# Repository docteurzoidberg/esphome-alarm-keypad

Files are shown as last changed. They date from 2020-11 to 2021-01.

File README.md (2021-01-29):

# Esphome Alarm Keypad

! README IN PROGRESS !

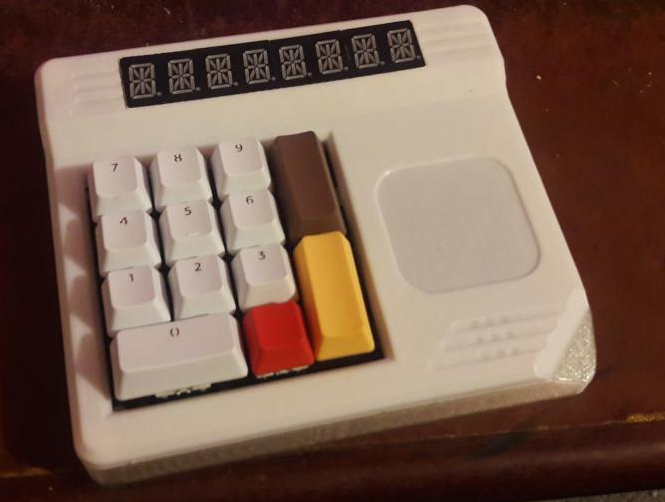
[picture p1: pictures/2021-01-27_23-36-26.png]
Alarm Keypad Picture


The Alarm Keypad is an interface to the Home Assistant Alarm Control Panel

//TODO: insert link here of ha alarm integration

Goal is to have a nice alarm control panel with lights, displays, rfid tag reader and a backup keypad to arm/disarm the Home Assistant alarm.

## Prototype video

protovideodemo (http://www.youtube.com/watch?v=kQHlJRchfG0 "prototype working with all features !")

## Features

- 13 key keyboard with mechanical switches . behind a pcf8574 i2c i/o expander
- per key adressable rgb backlight (13)
- pn532 rfid reader
- adressable led strip for case backlight
- adressable led ring for rfid feedback
- two 4 character alphanum displays with ht16k33 backpacks
- RTTTL sound output

## Hardware:

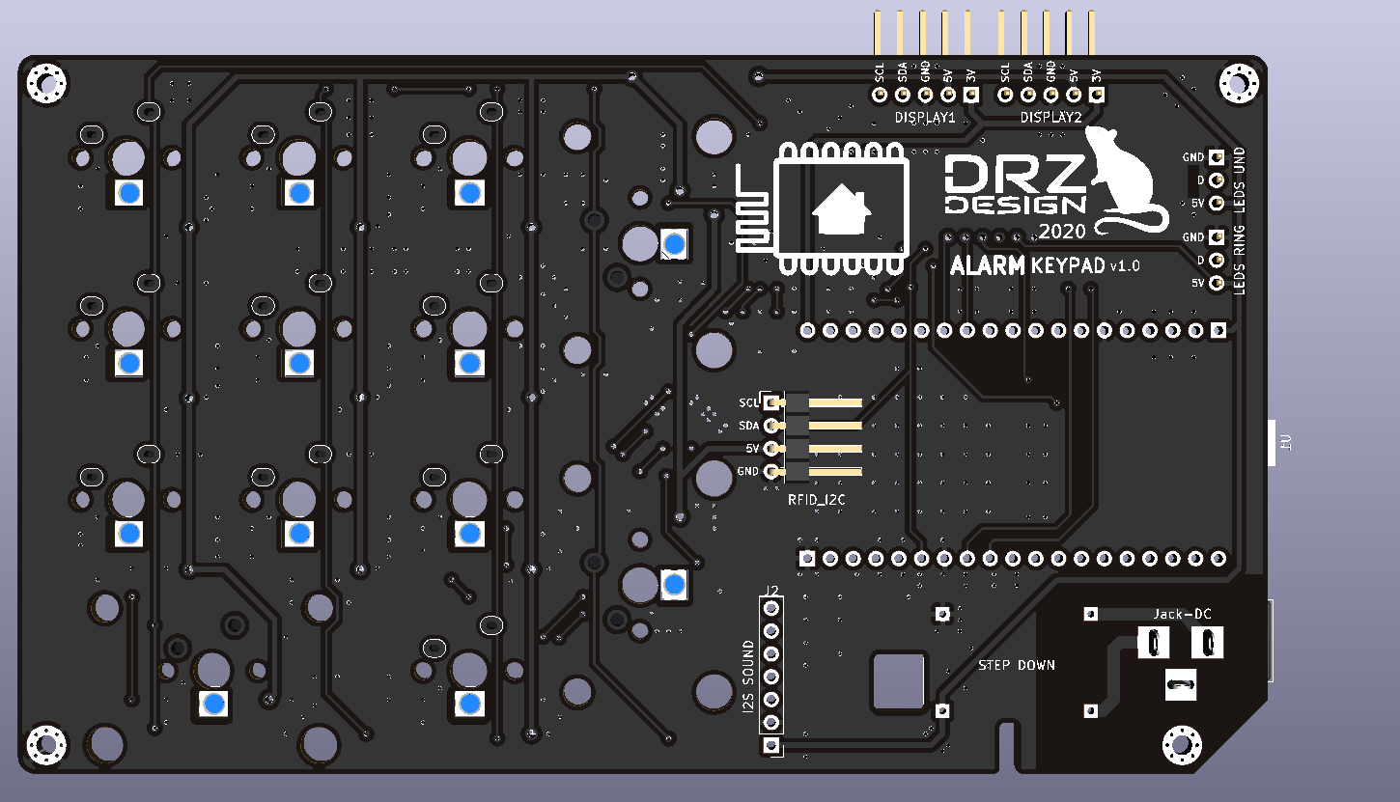
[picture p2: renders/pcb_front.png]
pcb front

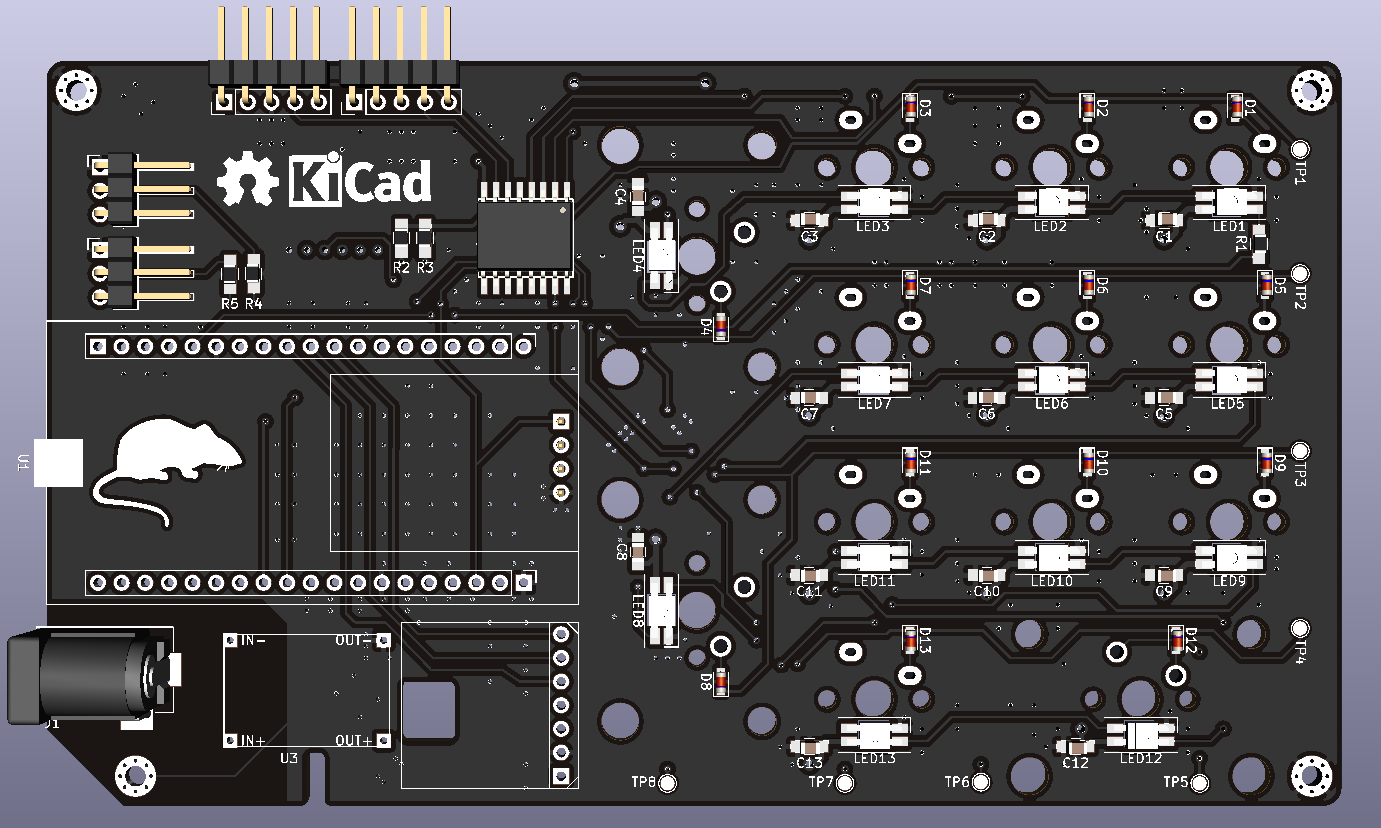
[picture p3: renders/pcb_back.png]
pcb_back


kicad/ contain the custom made pcb with all i/o from and to the esp, integrating the keypad with per key smd rgb backlight.

## Software:

//TODO: link to my-esphome github repo

### boot

    loading sequence on leds and screen

### connected

    show alarm state (armed/disarmed and so on)

### disconnected

    show "ERROR"

### rfid scan

    animate rfid led ring
    HA tag scanned service, changing alarm state if correct tag?

### key press

    flash key backlight in one color
    enter typing state

### typing

    show "code ?" + asterisk each pressed key until 4
    when 4 (allowed) keys pressed enter code check state
    start timer to enter typing timeout if no key pressed in X seconds

### typing timeout

    do something animated with case and keypad leds
    return back to alarm state mode

### code check

    display "check..." until we got a state change in HA alarm, or entering a 5sec timeout
    do something animated with case and keypad leds
### code check timeout

    HA alarm state didn't changed so the code is wrong or there is a problem
    display "FAIL" for 3 sec and go back to alarm state mode
    do something animated with case and keypad leds

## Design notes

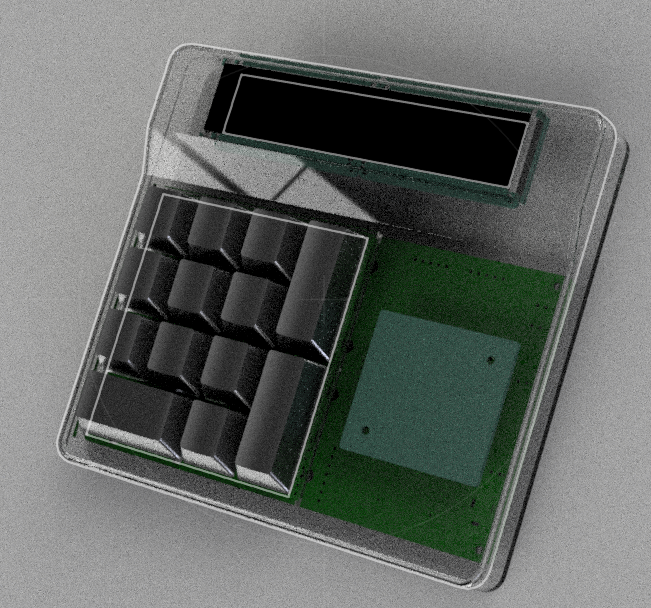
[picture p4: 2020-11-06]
renders/case3.png

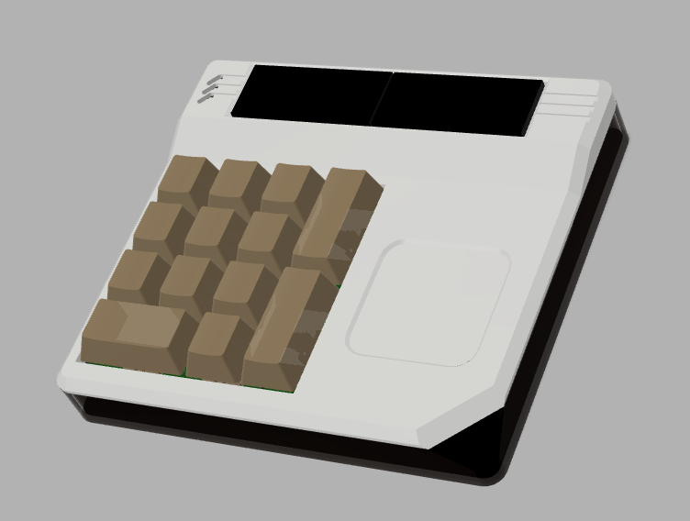
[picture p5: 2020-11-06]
renders/case2.png

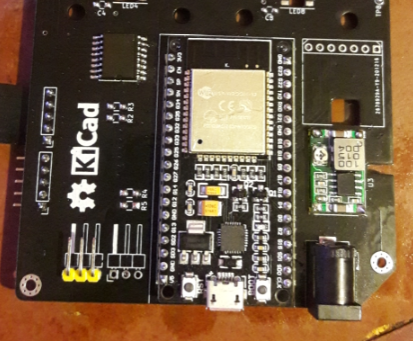
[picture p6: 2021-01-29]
pictures/2021-01-09_18.17.33.png

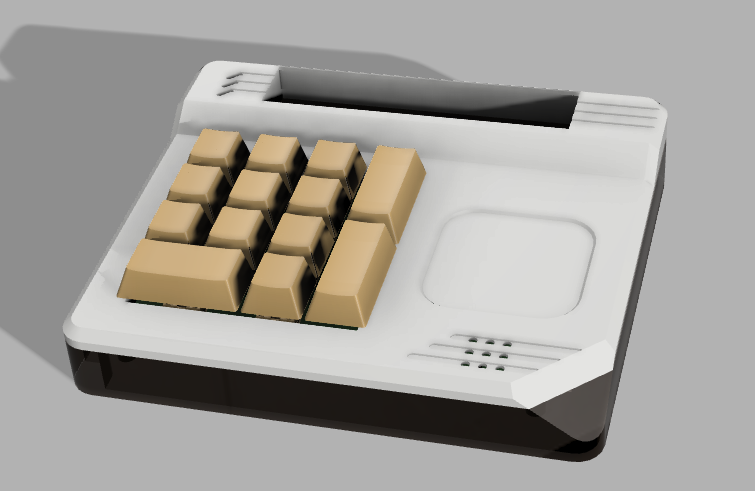
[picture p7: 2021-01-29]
renders/case.png

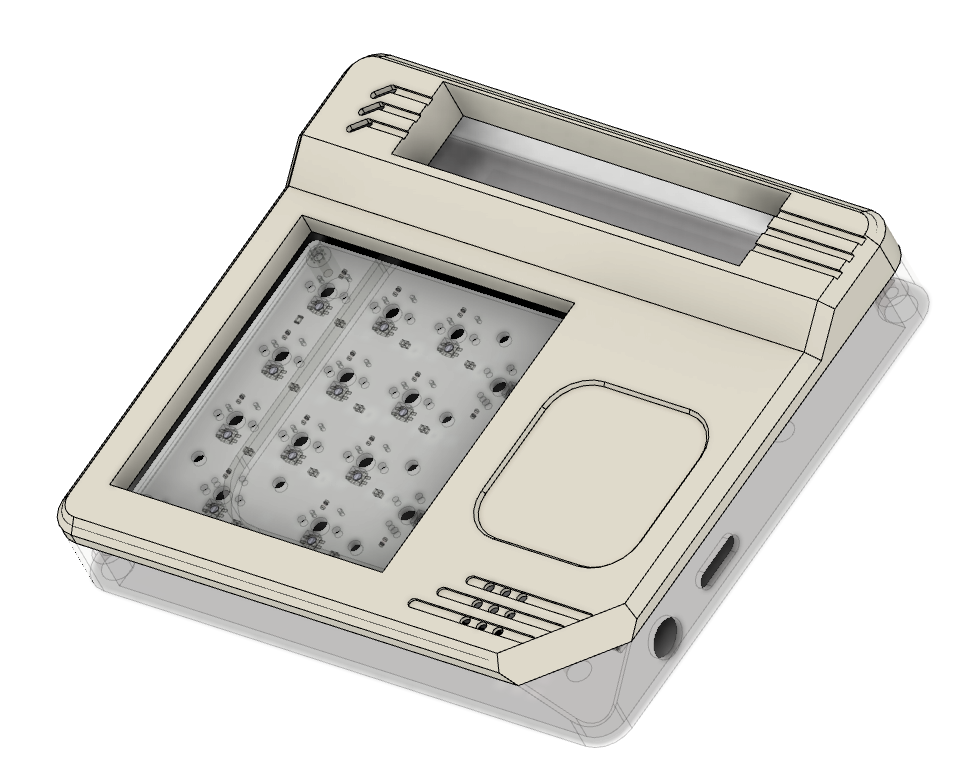
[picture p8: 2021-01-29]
renders/case_front.png

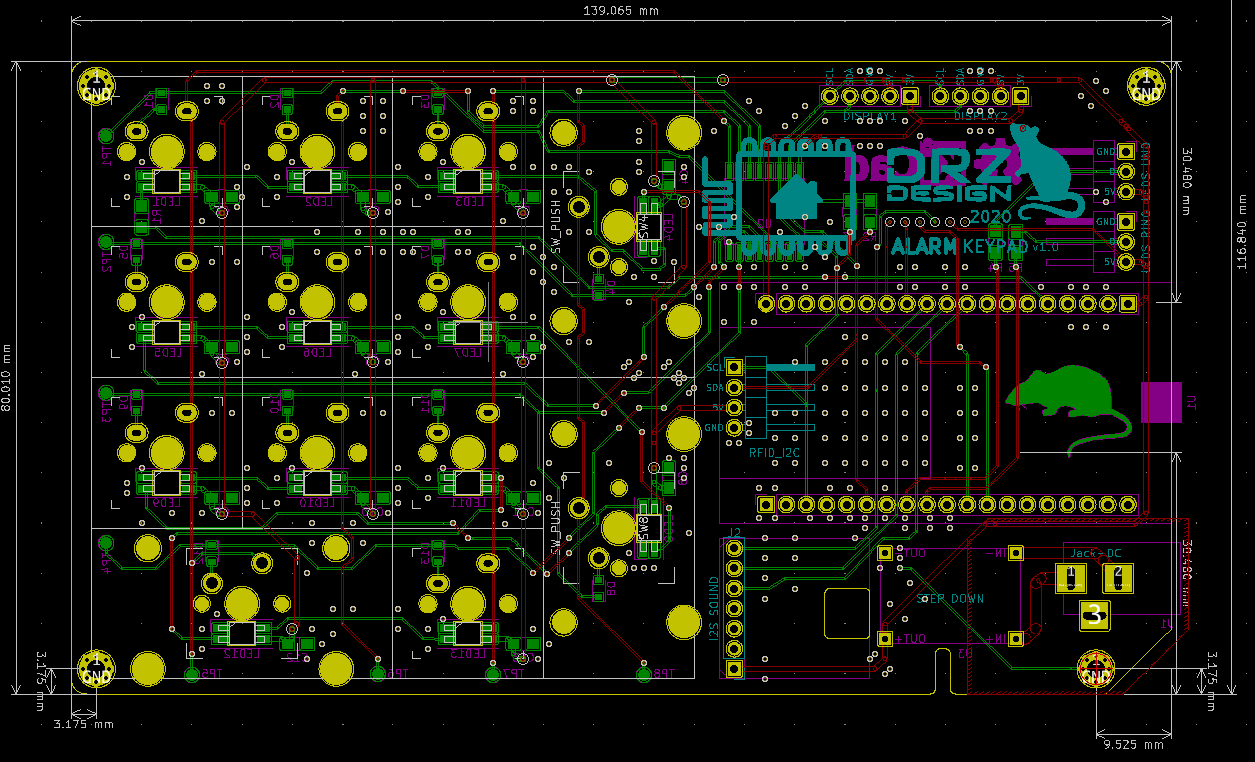
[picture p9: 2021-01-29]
renders/pcb.png

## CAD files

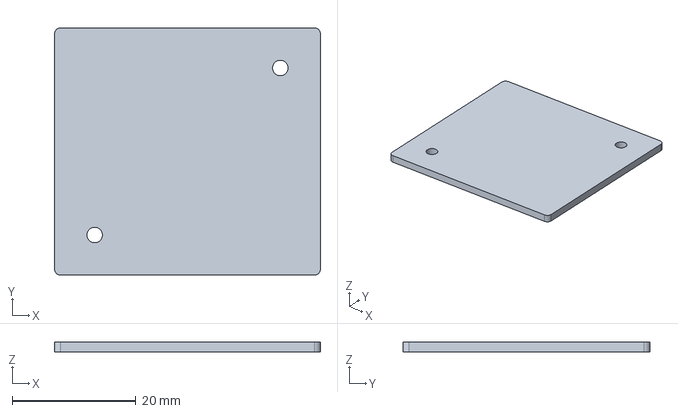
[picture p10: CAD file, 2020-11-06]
3d models/rfid module v2.step
43.0 x 40.0 x 1.60 mm

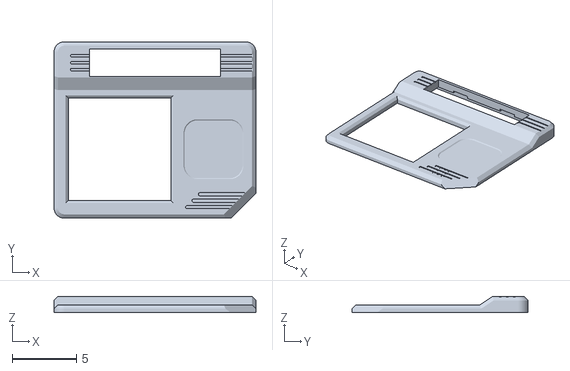
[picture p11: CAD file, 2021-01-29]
case/stl/case_haut.stl
15.7 x 13.7 x 1.26

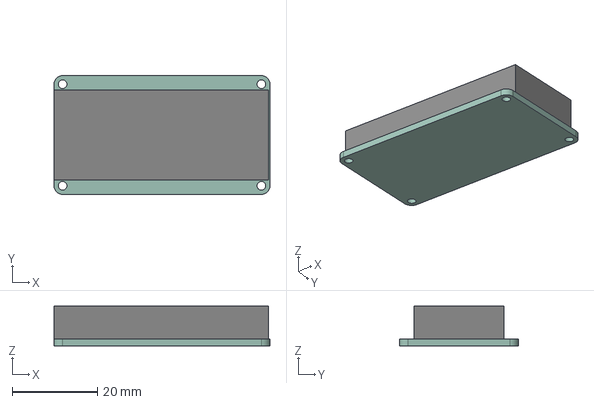
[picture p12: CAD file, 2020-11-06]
3d models/ht16k33 quad alpha backback v5.step
50.8 x 27.9 x 9.40 mm

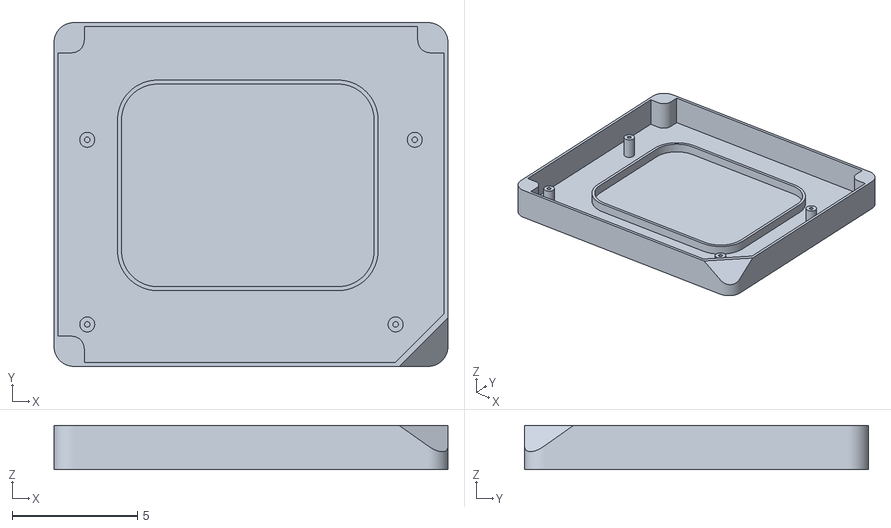
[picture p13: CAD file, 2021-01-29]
case/stl/case_bas.stl
15.7 x 13.7 x 1.76

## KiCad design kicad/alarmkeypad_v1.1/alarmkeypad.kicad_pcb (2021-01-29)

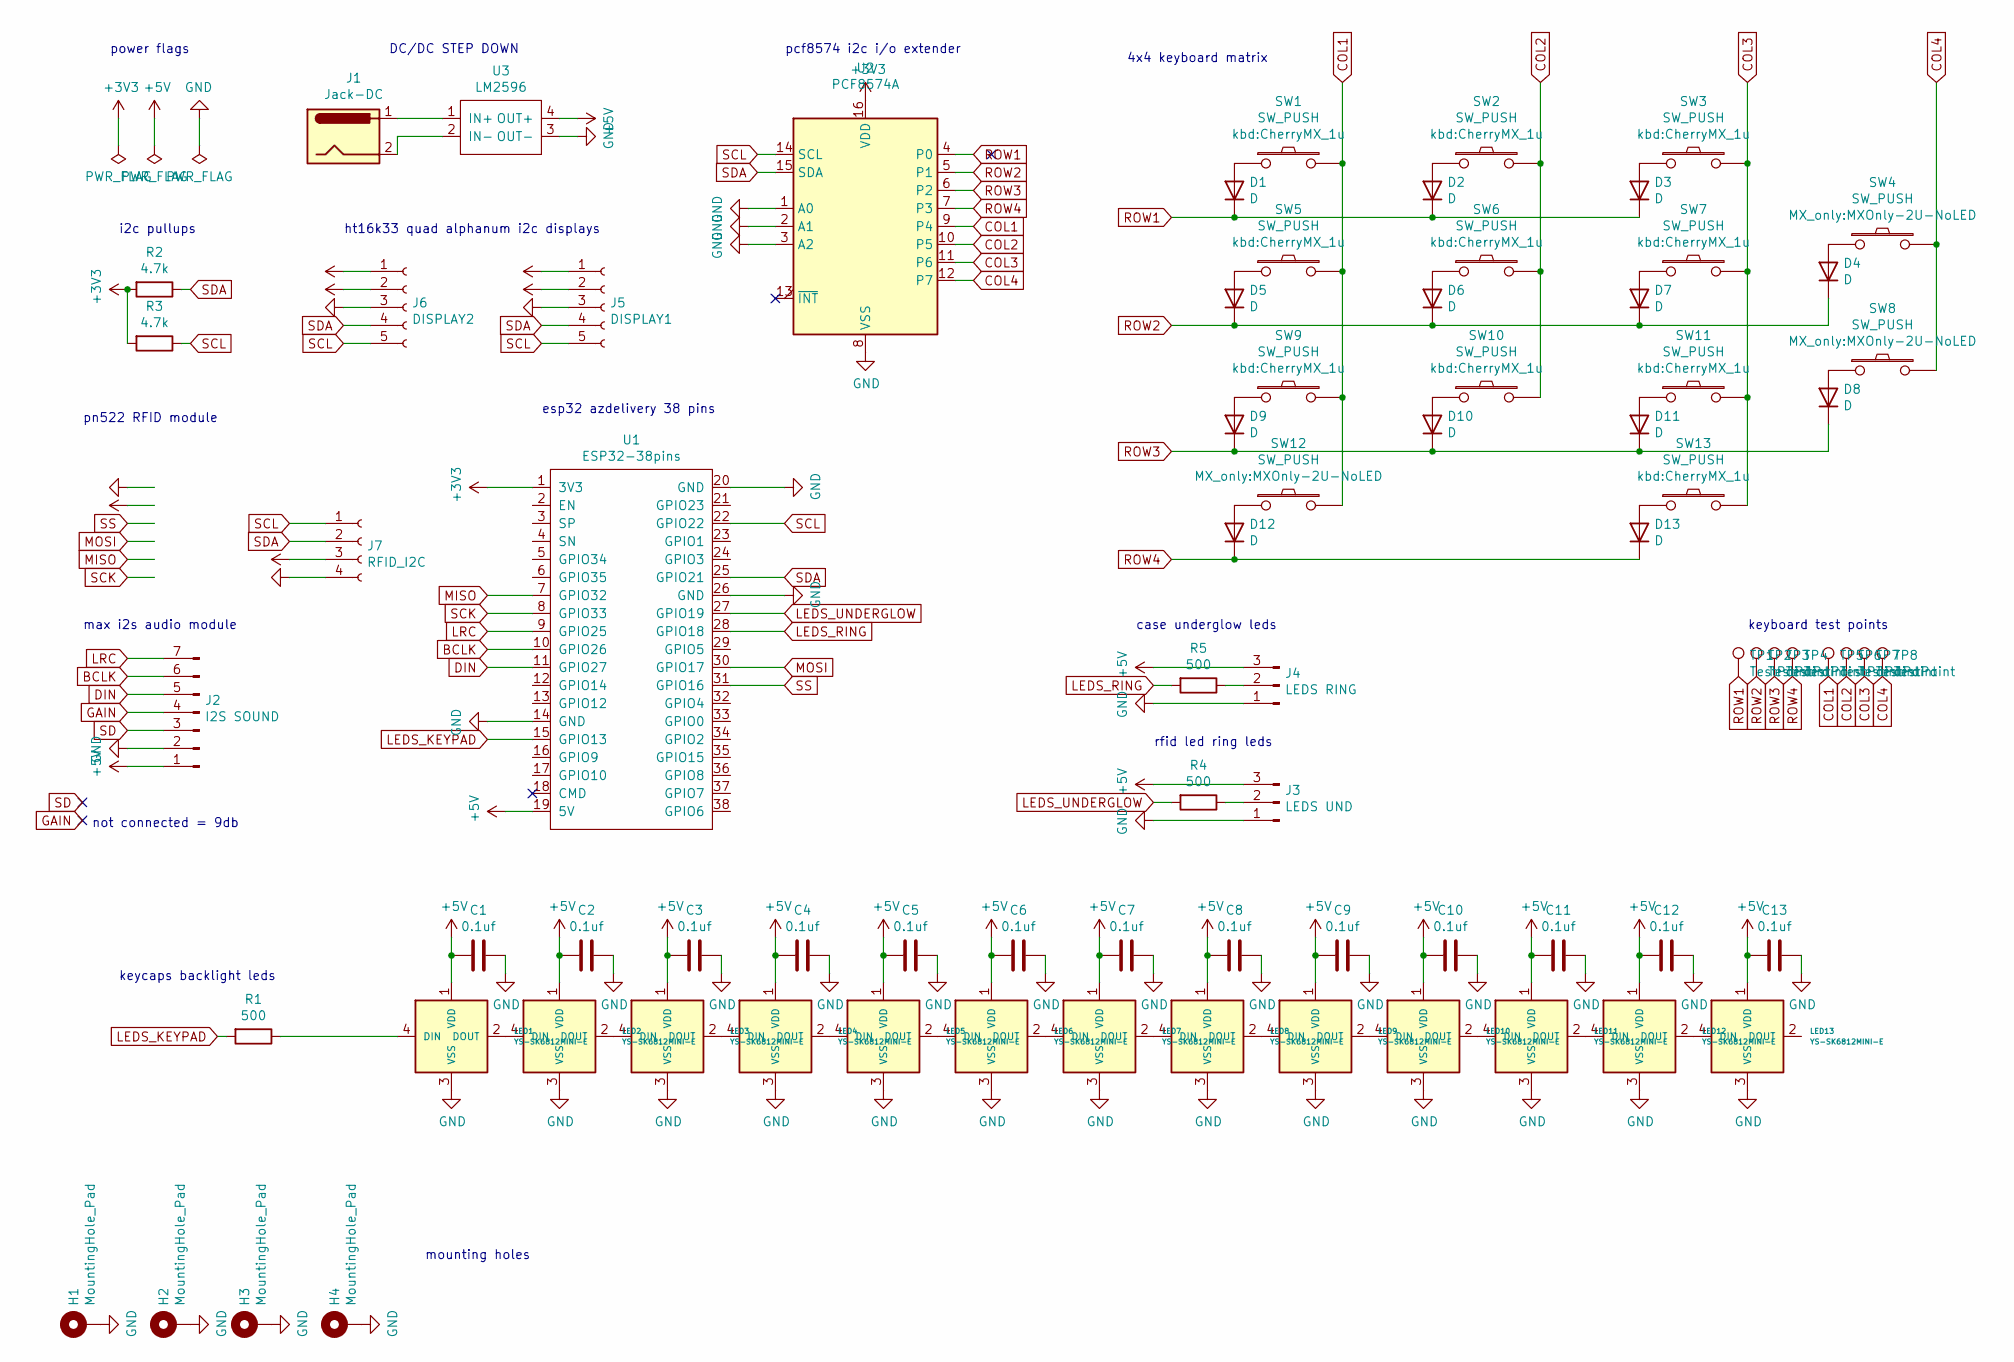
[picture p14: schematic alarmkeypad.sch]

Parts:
C1, C2, C3, C4, C5, C6, C7, C8, C9, C10, C11, C12, C13: 0.1uf; C_0805_HandSoldering
D1, D2, D3, D4, D5, D6, D7, D8, D9, D10, D11, D12, D13: D; D_0805
H1, H2, H3, H4: MountingHole_Pad; MountingHole_3.2mm_M3_Pad_Via
J1: Jack-DC; JACK_ALIM
J2: I2S SOUND; Pin_Header_Straight_1x07_Pitch2.54mm
J3: LEDS UND; Pin_Header_Angled_1x03_Pitch2.54mm
J4: LEDS RING; Pin_Header_Angled_1x03_Pitch2.54mm
J5: DISPLAY1; Pin_Header_Straight_1x05_Pitch2.54mm
J6: DISPLAY2; Pin_Header_Straight_1x05_Pitch2.54mm
J7: RFID_I2C; Pin_Header_Straight_1x04_Pitch2.54mm
LED1, LED2, LED3, LED4, LED5, LED6, LED7, LED8, LED9, LED10, LED11, LED12, LED13: YS-SK6812MINI-E
R1, R4, R5: 500; R_0805_HandSoldering
R2, R3: 4.7k; R_0805_HandSoldering
SW1, SW2, SW3, SW5, SW6, SW7, SW9, SW10, SW11, SW13: SW_PUSH; CherryMX_1u
SW4, SW8, SW12: SW_PUSH; MXOnly-2U-NoLED
TP1, TP2, TP3, TP4, TP5, TP6, TP7, TP8: TestPoint; TestPoint_Pad_D1.5mm
U1: ESP32-38pins; esp32 38pin azdelivery
U2: PCF8574A; SO-16-L
U3: LM2596; LM2596 module

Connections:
+3V3: J5.1, J6.1, R2.2, R3.2, U1.1 (3V3), U2.16 (VDD)
+5V: C1.1, C2.1, C3.1, C4.1, C5.1, C6.1, C7.1, C8.1, C9.1, C10.1, C11.1, C12.1, C13.1, J2.1, J3.3, J4.3, J5.2, J6.2, J7.3, LED1.1 (VDD), LED2.1 (VDD), LED3.1 (VDD), LED4.1 (VDD), LED5.1 (VDD), LED6.1 (VDD), LED7.1 (VDD), LED8.1 (VDD), LED9.1 (VDD), LED10.1 (VDD), LED11.1 (VDD), LED12.1 (VDD), LED13.1 (VDD), U1.19 (5V), U3.4 (OUT+)
BCLK: J2.6, U1.10 (GPIO26)
COL1: SW1.2, SW5.2, SW9.2, SW12.2, TP5.1, U2.9 (P4)
COL2: SW2.2, SW6.2, SW10.2, TP6.1, U2.10 (P5)
COL3: SW3.2, SW7.2, SW11.2, SW13.2, TP7.1, U2.11 (P6)
COL4: SW4.2, SW8.2, TP8.1, U2.12 (P7)
DIN: J2.5, U1.11 (GPIO27)
GAIN: J2.4
GND: C1.2, C2.2, C3.2, C4.2, C5.2, C6.2, C7.2, C8.2, C9.2, C10.2, C11.2, C12.2, C13.2, H1.1, H2.1, H3.1, H4.1, J2.2, J3.1, J4.1, J5.3, J6.3, J7.4, LED1.3 (VSS), LED2.3 (VSS), LED3.3 (VSS), LED4.3 (VSS), LED5.3 (VSS), LED6.3 (VSS), LED7.3 (VSS), LED8.3 (VSS), LED9.3 (VSS), LED10.3 (VSS), LED11.3 (VSS), LED12.3 (VSS), LED13.3 (VSS), U1.14 (GND), U1.20 (GND), U1.26 (GND), U2.1 (A0), U2.2 (A1), U2.3 (A2), U2.8 (VSS), U3.3 (OUT-)
LEDS_KEYPAD: R1.2, U1.15 (GPIO13)
LEDS_RING: R5.2, U1.28 (GPIO18)
LEDS_UNDERGLOW: R4.2, U1.27 (GPIO19)
LRC: J2.7, U1.9 (GPIO25)
MISO: U1.7 (GPIO32)
MOSI: U1.30 (GPIO17)
unnamed: D1.2 (A), SW1.1
unnamed: D2.2 (A), SW2.1
unnamed: D3.2 (A), SW3.1
unnamed: D4.2 (A), SW4.1
unnamed: D5.2 (A), SW5.1
unnamed: D6.2 (A), SW6.1
unnamed: D7.2 (A), SW7.1
unnamed: D8.2 (A), SW8.1
unnamed: D9.2 (A), SW9.1
unnamed: D10.2 (A), SW10.1
unnamed: D11.2 (A), SW11.1
unnamed: D12.2 (A), SW12.1
unnamed: D13.2 (A), SW13.1
unnamed: J1.1, U3.1 (IN+)
unnamed: J1.2, U3.2 (IN-)
unnamed: J3.2, R4.1
unnamed: J4.2, R5.1
unnamed: LED1.2 (DOUT), LED2.4 (DIN)
unnamed: LED1.4 (DIN), R1.1
unnamed: LED2.2 (DOUT), LED3.4 (DIN)
unnamed: LED3.2 (DOUT), LED4.4 (DIN)
unnamed: LED4.2 (DOUT), LED5.4 (DIN)
unnamed: LED5.2 (DOUT), LED6.4 (DIN)
unnamed: LED6.2 (DOUT), LED7.4 (DIN)
unnamed: LED7.2 (DOUT), LED8.4 (DIN)
unnamed: LED8.2 (DOUT), LED9.4 (DIN)
unnamed: LED10.2 (DOUT), LED11.4 (DIN)
unnamed: LED9.2 (DOUT), LED10.4 (DIN)
unnamed: LED11.2 (DOUT), LED12.4 (DIN)
unnamed: LED12.2 (DOUT), LED13.4 (DIN)
ROW1: D1.1 (K), D2.1 (K), D3.1 (K), TP1.1, U2.4 (P0)
ROW2: D4.1 (K), D5.1 (K), D6.1 (K), D7.1 (K), TP2.1, U2.5 (P1)
ROW3: D8.1 (K), D9.1 (K), D10.1 (K), D11.1 (K), TP3.1, U2.6 (P2)
ROW4: D12.1 (K), D13.1 (K), TP4.1, U2.7 (P3)
SCK: U1.8 (GPIO33)
SCL: J5.5, J6.5, J7.1, R3.1, U1.22 (GPIO22), U2.14 (SCL)
SD: J2.3
SDA: J5.4, J6.4, J7.2, R2.1, U1.25 (GPIO21), U2.15 (SDA)
SS: U1.31 (GPIO16)

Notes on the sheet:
DC/DC STEP DOWN
i2c pullups
ht16k33 quad alphanum i2c displays
4x4 keyboard matrix
keycaps backlight leds
case underglow leds
rfid led ring leds
keyboard test points
mounting holes
power flags
not connected = 9db
max i2s audio module
pn522 RFID module
pcf8574 i2c i/o extender
esp32 azdelivery 38 pins

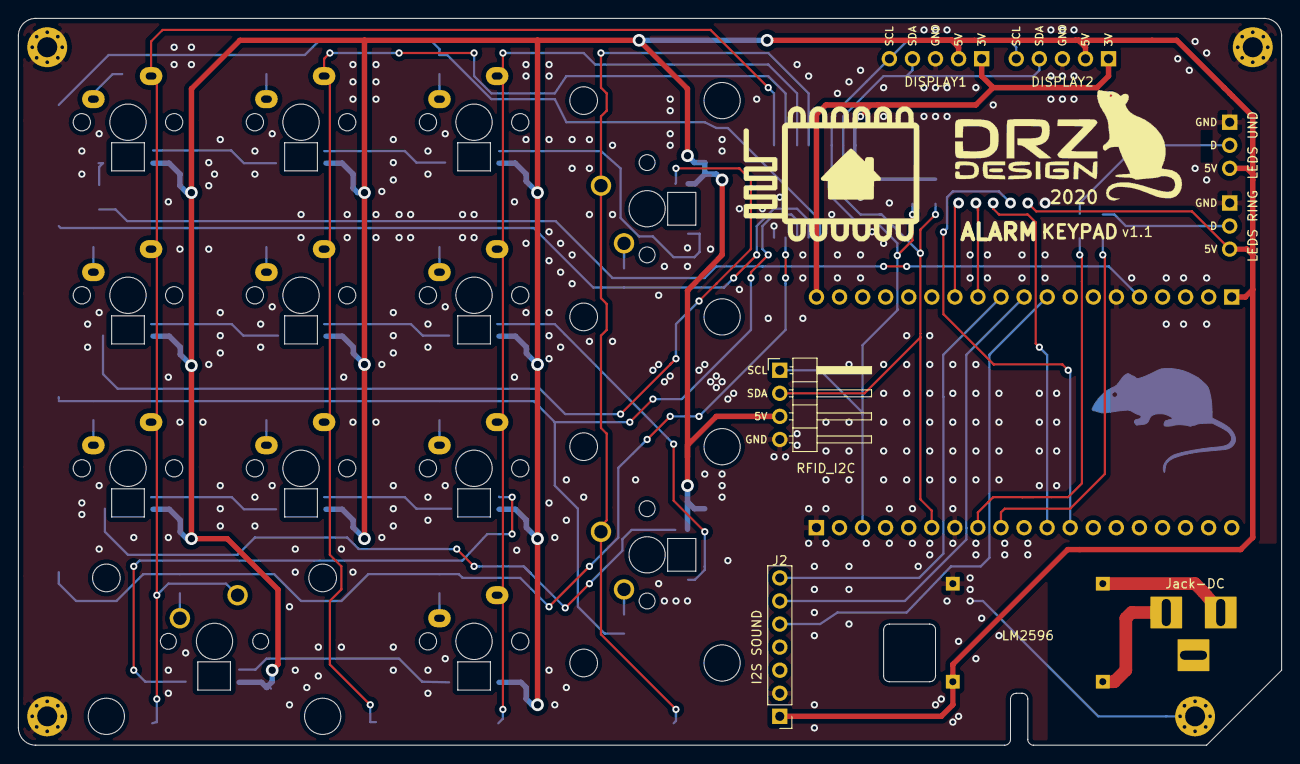
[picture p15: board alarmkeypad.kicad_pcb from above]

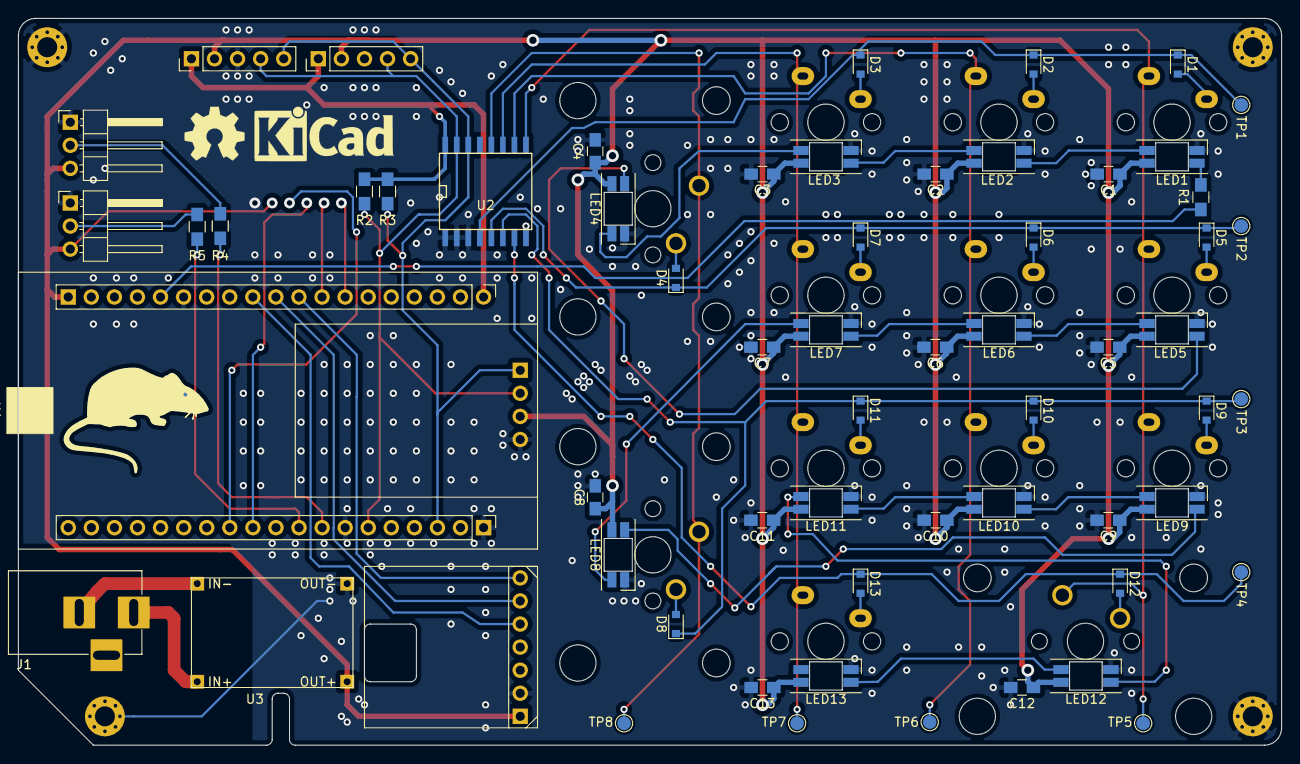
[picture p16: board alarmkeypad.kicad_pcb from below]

Board: 2 copper layers, 139.1 x 80.0 mm, 79 parts (60 on the bottom side), 49 nets.

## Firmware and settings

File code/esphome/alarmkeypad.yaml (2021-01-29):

substitutions:
  devicename: "alarmkeypad"
  friendly_name: "Alarm Keypad"

esphome:
  name: $devicename
  build_path: build/$devicename
  platform: ESP32
  board: esp32doit-devkit-v1
  on_boot:
    - priority: 1000
      then:
        - lambda: |-
            fastled_base_fastledlightoutput->get_controller()->setDither(0);
            id(mainobj).set_display(id(alpha));
            id(mainobj).set_alarmstatusentity(id(alarmtext));
            id(mainobj).set_keypadtext(id(reader));
    - priority: 600
      then:
        - lambda: |-
            id(mainobj).on_boot();
            id(alpha).set_brightness(.1);
        - light.turn_on:
            id: leds_keypad
            brightness: 0.2
            effect: keypad_boot_effect
        - light.turn_on:
            id: leds_case
            brightness: 0.2
            effect: case_boot_effect
  on_shutdown:
    then:
      - lambda: |-
          id(mainobj).on_shutdown();

wifi: !include "common/wifi.yaml"

captive_portal:

logger:
  level: ERROR

ota:

api:
  services:

    - service: rfidreader_tag_ok
      then:
      - rtttl.play: "beep:d=16,o=5,b=100:b"

    - service: rfidreader_tag_ko
      then:
      - rtttl.play: "beep:d=8,o=5,b=100:b"

    - service: play_rtttl
      variables:
        song_str: string
      then:
        - rtttl.play:
            rtttl: !lambda 'return song_str;'

output:
  - platform: ledc
    pin: GPIO25
    id: rtttl_out

i2c:
  sda: 21
  scl: 22

rtttl:
  output: rtttl_out
  id: buzzer
  on_finished_playback:
    - logger.log: 'Song ended!'

pn532_i2c:
  id: rfid
  update_interval: 1s
  on_tag:
    then:
    - homeassistant.tag_scanned: !lambda 'return x;'
    - rtttl.play: "success:d=24,o=5,b=100:c,g,b"

pcf8574:
  - id: 'pcf8574_hub'
    address: 0x38
    pcf8575: False

keypad:
  id: mykeypad
  rows:
    - pin:
        pcf8574: pcf8574_hub
        number: 0
        mode: INPUT
        inverted: False
    - pin:
        pcf8574: pcf8574_hub
        number: 1
        mode: INPUT
        inverted: False
    - pin:
        pcf8574: pcf8574_hub
        number: 2
        mode: INPUT
        inverted: False
    - pin:
        pcf8574: pcf8574_hub
        number: 3
        mode: INPUT
        inverted: False
  columns:
    - pin:
        pcf8574: pcf8574_hub
        number: 4
        mode: INPUT
        inverted: False
    - pin:
        pcf8574: pcf8574_hub
        number: 5
        mode: INPUT
        inverted: False
    - pin:
        pcf8574: pcf8574_hub
        number: 6
        mode: INPUT
        inverted: False
    - pin:
        pcf8574: pcf8574_hub
        number: 7
        mode: INPUT
        inverted: False
  keys: "789D456B123A0DDD"

display:
  - platform: ht16k33_alpha
    id: "alpha"
    address: 0x70
    secondary_displays:
      - address: 0x71
    update_interval : 33ms
    lambda: |-
      id(mainobj).display_lambdacall(it, id(text).state);

light:

  #Keypad adressable rgb backlight leds
  - platform: fastled_clockless
    id: leds_keypad
    chipset: WS2812B
    pin: 13
    num_leds: 13
    rgb_order: GRB
    name: "$friendly_name key backlight leds"
    gamma_correct: 0
    color_correct: [30%, 30%, 30%]
    effects:
      - addressable_rainbow:
          name: Rainbow
      - addressable_scan:
          name: keypad_boot_effect
          move_interval: 22ms
          scan_width: 3
      - addressable_lambda:
          name: "render"
          update_interval: 16ms
          lambda: |-
            id(mainobj).leds_keypad_lambdacall(it);

  #Case inside glow adressable rgb leds
  - platform: fastled_clockless
    id: leds_case
    chipset: WS2812B
    pin: 19
    num_leds: 22
    rgb_order: GRB
    name: "$friendly_name case glow leds"
    gamma_correct: 0
    color_correct: [30%, 30%, 30%]
    effects:
      - addressable_rainbow:
          name: Rainbow
      - addressable_scan:
          name: case_boot_effect
          move_interval: 22ms
          scan_width: 4
      - addressable_lambda:
          name: "render"
          update_interval: 22ms
          lambda: |-
            id(mainobj).leds_case_lambdacall(it);

  #Rfid status addressable rgb led ring
  - platform: fastled_clockless
    id: leds_rfid
    chipset: WS2812B
    pin: 18
    num_leds: 8
    rgb_order: GRB
    name: "$friendly_name Rfid ring leds"
    gamma_correct: 0
    color_correct: [50%, 50%, 50%]
    effects:
      - addressable_rainbow:
          name: Rainbow
      - addressable_lambda:
          name: "render"
          update_interval: 22ms
          lambda: |-
            id(mainobj).leds_rfid_lambdacall(it);
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
